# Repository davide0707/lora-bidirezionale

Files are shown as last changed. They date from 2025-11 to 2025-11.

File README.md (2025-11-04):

# Sistema di Comunicazione LoRa Bidirezionale con SCL3300
## Implementazione Embedded su STM32WLE5 (LoRa-E5 Mini) e Gateway RAK7268V2

## Abstract
Questo progetto realizza un sistema completo di comunicazione LoRaWAN bidirezionale tra una scheda LoRa-E5 Mini (STM32WLE5) e un gateway RAK7268V2. Il firmware, scritto in C con STM32CubeIDE, sostituisce integralmente il vecchio firmware AT e implementa: join OTAA autonomo, gestione uplink/downlink, acquisizione da sensore SCL3300 via SPI, calibrazione automatica, filtraggio EMA ottimizzato e pipeline di codifica/decodifica (binario → HEX → Base64). L’infrastruttura lato rete utilizza MQTT (Mosquitto) e una dashboard web per visualizzazione dati e comandi remoti. La soluzione è plug & play: una volta allineate le chiavi OTAA su gateway e firmware, la comunicazione si avvia senza ulteriori interventi.

---

## Caratteristiche
- Comunicazione LoRaWAN bidirezionale su banda EU868.
- Join OTAA già integrato nel firmware, con gestione autonoma dello stato di rete.
- Firmware custom in C (STM32CubeIDE) senza dipendenza da comandi AT.
- Driver proprietario per sensore Murata SCL3300 via SPI, con verifica WHOAMI.
- Calibrazione automatica iniziale (100 campioni) e filtro EMA sui tre assi.
- Pipeline dati: acquisizione → filtraggio → impacchettamento 16 byte → HEX → Base64.
- Dashboard web con grafico in tempo reale, log eventi e comandi remoti (es. calibrazione).
- Integrazione MQTT (Mosquitto) per telemetria e controllo.
- PCB personalizzato con LoRa-E5 + SCL3300 (circa 40 mm × 20 mm).

---

## Architettura di Sistema

[ SCL3300 (SPI) ]
│
▼
[ LoRa-E5 Mini - STM32WLE5 ]
• Firmware C
• Driver SCL3300
• EMA
• LoRaWAN (OTAA)
│ LoRa EU868
▼
[ Gateway RAK7268V2 ]
• Application (OTAA)
• Forwarder MQTT
│ Ethernet/Wi-Fi
▼
[ Broker MQTT (Mosquitto) ]
│
▼
[ Web Dashboard ]

---

## Requisiti Tecnici

### Hardware
- Scheda LoRa-E5 Mini (STM32WLE5).
- Sensore Murata SCL3300 collegato via SPI.
- Gateway LoRaWAN RAK7268V2.
- PC di sviluppo con interfaccia ST-Link o equivalente per flashing/debug.
- PCB personalizzato (opzionale, dimensioni circa 4 × 2 cm).

### Software
- STM32CubeIDE (versione recente).
- Toolchain GCC ARM Embedded integrata in STM32CubeIDE.
- Mosquitto MQTT Broker.
- Browser moderno per la dashboard web.
- Facoltativi: utilità per monitor seriale (es. PuTTY), Node.js se si estende la dashboard.

---

## Struttura del Repository

/Firmware
project (STM32CubeIDE)

/Web
interfaccia

/Docs
spiegazione dettagliata

/LICENSE
/README.md

---

## Dettagli Firmware

### Flusso di avvio
1. Inizializzazione clock, GPIO, SPI, UART/USART (log opzionale).
2. Inizializzazione stack LoRaWAN; caricamento parametri OTAA (DevEUI, AppEUI/JoinEUI, AppKey).
3. Join OTAA; al completamento, disattivazione del LED rosso lampeggiante come indicatore di rete attiva.
4. Inizializzazione SCL3300: verifica WHOAMI, settaggio modalità operativa da datasheet.
5. Calibrazione automatica: acquisizione 100 campioni, calcolo offset per X/Y/Z.
6. Loop di misura: lettura dati, applicazione filtro EMA, impacchettamento payload, invio periodico uplink. Gestione downlink per comandi remoti (es. ri-calibrazione).

### Filtro EMA
- Implementazione su ciascun asse: `y[n] = α·x[n] + (1−α)·y[n−1]`.
- Valore predefinito α tipicamente compreso tra 0,1 e 0,3 (configurabile in `app_config.h`).

### Indicatori di stato
- LED rosso lampeggiante: dispositivo in join/ricerca rete.
- LED rosso spento: join completato, rete attiva.
- Messaggi UART opzionali: log diagnostico di inizializzazione, WHOAMI, calibrazione, errori.

---

## Formato dei Dati e Codifica

### Payload binario (uplink)
- Dimensione: 16 byte totali.
- Struttura (little-endian consigliato):
  - Byte 0–3: Asse X (float IEEE-754 32-bit) oppure int32 scalato.
  - Byte 4–7: Asse Y (float 32-bit) oppure int32 scalato.
  - Byte 8–11: Asse Z (float 32-bit) oppure int32 scalato.
  - Byte 12–15: Temperatura interna (float 32-bit) oppure int32 scalato.
- Nota: per deployment a basso overhead si consiglia la rappresentazione int32 scalata (es. mdeg o mg) documentando i fattori di scala in `payload_format.md`.

### Pipeline di trasmissione
1. Acquisizione → filtraggio EMA → normalizzazione/scala → packing binario 16 byte.
2. Conversione in HEX.
3. Codifica Base64 per inoltro su MQTT, quando previsto dal flusso gateway.

### Pipeline di ricezione (lato server/dashboard)
1. Base64 → HEX → binario.
2. Parse dei 4 campi (X, Y, Z, T).
3. Applicazione fattori di scala inversi o interpretazione float IEEE-754.

### Esempio di decodifica (JavaScript, valori float 32-bit little-endian)
```js
function decodeBase64Payload(b64) {
  const raw = atob(b64); // stringa binaria
  const bytes = new Uint8Array([...raw].map(c => c.charCodeAt(0)));
  const view = new DataView(bytes.buffer);
  const x = view.getFloat32(0, true);
  const y = view.getFloat32(4, true);
  const z = view.getFloat32(8, true);
  const t = view.getFloat32(12, true);
  return { x, y, z, t };
}
```

## Comandi Remoti (Downlink)

- **Calibrazione remota**: comando per ri-avviare la sequenza di offset (100 campioni).
- **Reset filtro EMA**: re-inizializza gli stati dei tre canali.
- **Parametrizzazione**: aggiornamento del coefficiente α dell’EMA, del periodo di uplink e delle soglie di warning.

I comandi sono ricevuti e interpretati nel firmware (callback di downlink), con ack opzionale via uplink.

---

## Configurazione del Gateway RAK7268V2 (OTAA)

1. Creare un’applicazione LoRaWAN nel gateway.
2. Registrare il dispositivo in modalità OTAA, annotando **DevEUI**, **JoinEUI (AppEUI)** e **AppKey**.
3. Impostare la **regione EU868** e un profilo di data rate adeguato.
4. Abilitare l’inoltro a un **broker MQTT** (interno/esterno), specificando topic e credenziali.
5. Verificare la corrispondenza dei parametri anche nel firmware (`app_config.h`):
   - `DEV_EUI`, `JOIN_EUI`, `APP_KEY`.
6. Riavviare il nodo: al join completato, l’indicatore **LED rosso si spegne**.

---

## Build e Flash (STM32CubeIDE)

### Import del progetto
- `File → Import → Existing Projects into Workspace` → selezionare la cartella `/Firmware`.
- Verificare la toolchain (GCC for STM32) e le opzioni di ottimizzazione.

### Configurazione
- Aggiornare `app_config.h` con chiavi OTAA e parametri operativi (α EMA, periodo uplink, pin SPI).
- Verificare i pin SPI per SCL3300 (MOSI/MISO/SCK/CS) e GPIO LED.

### Compilazione e flash
- Build del progetto in modalità **Release**.
- Collegare **ST-Link**, eseguire `Run → Debug/Run`.
- Opzionale: abilitare retarget UART per log su seriale.

---

## Installazione e Avvio (Plug & Play)

1. Flash del firmware sulla **LoRa-E5 Mini**.
2. Collegamento fisico **SCL3300** su bus **SPI** come da schemi (vedi `/Docs/schematic.pdf`).
3. Configurazione del gateway **RAK7268V2** in **OTAA** con le stesse chiavi del firmware.
4. Avvio **broker Mosquitto** e, se previsto, servizio di decoding.
5. Alimentazione del nodo: il dispositivo esegue **join**, si **calibra** e avvia gli **uplink** secondo il periodo configurato.

---

## Dashboard Web

- File nella cartella `/Web` (HTML/CSS/JS, Chart.js o libreria equivalente).
- Connessione a broker **MQTT** via **WebSocket** (se abilitato) o tramite un backend di bridging.

### Visualizzazioni
- Trend di **X / Y / Z / Temperatura**.
- Log eventi (**join**, **uplink**, **downlink**).
- Stato rete e ultimo **RSSI/SNR** (se disponibili nei metadati).

### Pannello comandi
- Pulsante **calibrazione remota**.
- Impostazione parametri (**α EMA**, **periodo uplink**).

---

## Prestazioni e Considerazioni

- **Filtraggio**: l’EMA riduce il rumore preservando la dinamica; scegliere α in funzione della latenza accettabile.
- **Consumi**: per nodi a batteria, ottimizzare duty-cycle, data rate, potenza TX e sleep tra misure.
- **Affidabilità**: verificare retry LoRaWAN, conferme ACK e politiche di rejoin.
- **Sicurezza**: mantenere segrete le chiavi OTAA; usare **TLS** per il trasporto MQTT su reti pubbliche.

---

## PCB e Collegamenti

- PCB personalizzato con integrazione **LoRa-E5 + SCL3300**.
- Dimensioni indicative: **40 mm × 20 mm**.
- Vedere `/Docs/schematic.pdf` e `/Docs/pcb_layout.png` per pinout e footprint.
- Layout consigliato: tracce SPI corte, piano di massa continuo, separazione RF/analogico.

---

## Troubleshooting

- **Join non riuscito**: verificare regione **EU868**, chiavi OTAA e copertura gateway.
- **WHOAMI fallito**: controllare cablaggio SPI, CS, frequenza clock e alimentazione sensore.
- **Dati errati o saturi**: rivedere scala fisica/offset; eseguire **calibrazione remota**.
- **Dashboard vuota**: controllare connessione MQTT, topic e decoder **Base64/HEX**.

---

## Licenza

Questo progetto è distribuito con licenza **MIT**. Vedere il file `LICENSE` per i dettagli.

---

## Riferimenti

- Murata, **SCL3300 Datasheet**.
- STMicroelectronics, **STM32WLE5 Reference Manual (RM0461)** e HAL Drivers.
- LoRa Alliance, **LoRaWAN 1.0.4 Specification**.
- RAKwireless, **Documentazione RAK7268V2**.
- Eclipse Mosquitto, **Documentazione MQTT**.

---

## Autore e Contatti

<p align="center"><strong>Autore: DI FILIPPO DAVIDE</strong></p>

<!-- GitHub Profile Button -->
<div align="center" style="margin-top: 20px;">
  <a href="https://github.com/davide0707">
    
  </a>
</div>

<!-- Contact Section -->
<h3 align="center" style="margin-top: 40px; font-family: 'Arial', sans-serif; color: #2C3539; font-size: 2em;">📬 Contact Me</h3>
<div align="center" style="font-family: 'Arial', sans-serif; color: #333; margin-top: 15px;">
  <p>
    
    <strong>E-mail:</strong> difilippodavide.github@gmail.com
  </p>
  <p>
    
    <strong>GitHub:</strong> <a href="https://github.com/davide0707" style="color: #3C76D7;">davide0707</a>
  </p>
</div>

<p align="center"><strong>Anno: 2025</strong></p>

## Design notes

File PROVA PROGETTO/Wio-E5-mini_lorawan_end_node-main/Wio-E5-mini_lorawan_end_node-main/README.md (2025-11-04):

# Wio-E5-mini_lorawan_end_node
LoRaWAN End Node app built from scratch with CubeMX for STM32WLE5JCx in the Wio-E5 mini.

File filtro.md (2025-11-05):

# LoRa + SCL3300 — Calibrazione, EMA Adattivo (Scalare & Circolare) e Pipeline Dati

---

## Indice

1. [Panoramica](#panoramica)
2. [Prerequisiti & File](#prerequisiti--file)
3. [Notazione & Convenzioni](#notazione--convenzioni)
4. [Calibrazione degli offset (media statica)](#calibrazione-degli-offset-media-statica)
5. [EMA adattivo (scalare)](#ema-adattivo-scalare)
   - [Ricorrenza EMA base](#ricorrenza-ema-base)
   - [Innovazione, media/varianza esponenziale](#innovazione-mediavarianza-esponenziale)
   - [Significatività → α adattivo](#significatività--α-adattivo)
   - [Update dello stato](#update-dello-stato)
6. [EMA adattivo circolare (angoli in gradi)](#ema-adattivo-circolare-angoli-in-gradi)
   - [Wrap & distanza angolare](#wrap--distanza-angolare)
   - [Media circolare con cos/sin](#media-circolare-con-cossin)
   - [Passi d’aggiornamento](#passi-daggiornamento)
7. [Parametri, significato e trade-off](#parametri-significato-e-trade-off)
8. [Mappatura codice ⇄ matematica](#mappatura-codice--matematica)
9. [Sequenza: init, calibrazione, run](#sequenza-init-calibrazione-run)
10. [Aggiornamento periodico & log](#aggiornamento-periodico--log)
11. [Payload LoRa (opzionale)](#payload-lora-opzionale)
12. [Considerazioni numeriche & temporali](#considerazioni-numeriche--temporali)
13. [Tuning pratico passo-passo](#tuning-pratico-passo-passo)
14. [Esempi di codice](#esempi-di-codice)
15. [Debug & Troubleshooting](#debug--troubleshooting)
16. [Licenza](#licenza)

---

## Panoramica

**Obiettivo:** ottenere valori stabili e reattivi.  
Catena di elaborazione (per ogni campione):

1. **Lettura registri**: `READ_ANG_X/Y/Z`, `READ_TEMPERATURE`.
2. **Compensazione offset**: sottrazione `o_X/o_Y/o_Z` calcolati a fermo.
3. **Filtraggio:**
   - **Temperatura** → **EMA scalare** (IIR 1° ordine con α adattivo).
   - **Angoli** → **EMA circolare** (gestisce il wrap ±180°).
4. **Output**: valori filtrati su UART + (opz.) impacchettati per LoRa.

```
[SCL3300] ──► [Offset Calib] ──► [EMA-Adaptive: T] ──►
                         └──► [EMA-Circular: X/Y/Z] ──► [UART/LoRa]
```

---

## Prerequisiti & File

- MCU con SPI + UART + stack LoRa (opz.).
- File di progetto tipici:
  - `scl3300.c/.h` — driver sensore e funzioni di lettura.
  - `ema_adaptive.h/.c` — implementazione dei filtri.
  - `main.c` — init, loop, logging, payload.

---

## Notazione & Convenzioni

- **Gradi**: angoli in **°**.
- **Wrap**: intervallo **(−180, 180]**.
- **Simboli comuni**:
  - `x_k`: campione corrente
  - `y_k`: uscita filtrata
  - `α`: gain EMA (0 < α ≤ 1)
  - `β`: fattore di “memoria” per stime esponenziali (0 < β < 1)
  - `ε`: piccolo stabilizzatore numerico (es. 1e−6)

---

## Calibrazione degli offset (media statica)

**Matematica.** Con N campioni a fermo:

$$
o_X=\frac{1}{N}\sum_{i=1}^N x_i,\quad
o_Y=\frac{1}{N}\sum_{i=1}^N y_i,\quad
o_Z=\frac{1}{N}\sum_{i=1}^N z_i
$$

Compensazione per i campioni successivi:

$$
\tilde{x}_k=x_k-o_X,\quad
\tilde{y}_k=y_k-o_Y,\quad
\tilde{z}_k=z_k-o_Z
$$

**Nota pratica:** usare **N=100..300**; evitare vibrazioni; fissare il dispositivo.

---

## EMA adattivo (scalare)

### Ricorrenza EMA base

$$
y_k = y_{k-1} + \alpha\,(x_k - y_{k-1}),\quad 0<\alpha\le 1
$$

- α **grande** → più reattivo (meno smoothing)
- α **piccolo** → più liscio (più ritardo)

### Innovazione, media/varianza esponenziale

$$
\begin{aligned}
e_k &= x_k - y_{k-1} \\
m_k &= \beta\,m_{k-1} + (1-\beta)\,e_k \\
d_k &= e_k - m_k \\
s_k^2 &= \beta\,s_{k-1}^2 + (1-\beta)\,d_k^2
\end{aligned}
$$

- `m_k`: tendenza lenta dell’innovazione
- `d_k`: residuo centrato
- `s_k`: deviazione standard stimata

### Significatività → α adattivo

$$
u_k = \frac{|d_k|}{s_k + \varepsilon},\qquad
\alpha_k = \alpha_{\min} + (\alpha_{\max}-\alpha_{\min})\frac{u_k^p}{1+u_k^p}
$$

- **Quiete**: \(u\approx0 \Rightarrow \alpha\approx\alpha_{\min}\)
- **Transitorio**: \(u\gg1 \Rightarrow \alpha\rightarrow\alpha_{\max}\)

### Update dello stato

$$
y_k = y_{k-1} + \alpha_k\,(x_k - y_{k-1})
$$

---

## EMA adattivo circolare (angoli in gradi)

### Wrap & distanza angolare

Funzione wrap in \((-180,180]\):

```c
static inline float wrap_deg(float a) {
    if (a <= -180.0f) return a + 360.0f;
    if (a >  180.0f)  return a - 360.0f;
    return a;
}
```

Innovazione angolare:

$$
e_k^\theta = \mathrm{wrap}(\theta_k - y_{k-1}^\theta)
$$

> **Importante**: il calcolo di \( \alpha_k \) usa **questa** innovazione “wrapped”.

### Media circolare con cos/sin

$$
\begin{aligned}
c_k &= (1-\alpha_k)\,c_{k-1} + \alpha_k\cos(\theta_k) \\
s_k &= (1-\alpha_k)\,s_{k-1} + \alpha_k\sin(\theta_k) \\
y_k^\theta &= \mathrm{atan2}(s_k, c_k)\quad[\text{gradi}]
\end{aligned}
$$

- \((c,s)\) rappresenta coerentemente la media su cerchio.
- Si evita il “salto” 179° → −179° trattandolo come **+2°**, non **−358°**.

### Passi d’aggiornamento

1. **Errore angolare**: \( e = \mathrm{wrap}(\theta - y^\theta) \)
2. **Stime esponenziali**: \( m, s^2 \) su \( e \)
3. **u → α** (curva “soft”)
4. **Media circolare** con \( \alpha \) calcolato al punto 3.

---

## Parametri, significato e trade-off

| Parametro | Ruolo | Tipico | Effetto/Trade-off |
|---|---|---|---|
| `EMA_ALPHA_MIN`  | α in quiete | 0.02 … 0.08 | Più piccolo = più liscio ma maggiore ritardo |
| `EMA_ALPHA_MAX`  | α in transitorio | 0.3 … 0.7 | Più grande = più reattivo ma meno smoothing |
| `EMA_BETA` | memoria stime esponenziali | 0.98 … 0.995 | Alto = stima rumore più stabile ma più lenta |
| `EMA_PWR_P` | ripidità mappatura \(u\to\alpha\) | 2 (quadratico) | Più alto = transizione più brusca |
| `EMA_EPS` | stabilizzatore numerico | 1e−6 … 1e−4 | Evita div/0; non alterare troppo la dinamica |

**Regola d’oro:** inizia con *(0.04, 0.5, 0.99, 2, 1e−6)*, poi affina.

---

## Mappatura codice ⇄ matematica

| Matematica | Codice (concetto) |
|---|---|
| \( e_k = x_k - y_{k-1} \) | `e = x - y;` |
| \( m_k = \beta m_{k-1} + (1-\beta)e_k \) | `m = β*m + (1-β)*e;` |
| \( d_k = e_k - m_k \) | `de = e - m;` |
| \( s_k^2 = \beta s_{k-1}^2 + (1-\beta) d_k^2 \) | `s2 = β*s2 + (1-β)*de*de;` |
| \( u_k = |d_k|/(s_k+\varepsilon) \) | `u = fabs(de)/(sqrt(s2)+EPS);` |
| \( \alpha_k = \alpha_\min + (\alpha_\max-\alpha_\min)\frac{u^p}{1+u^p} \) | `a = αmin + (αmax-αmin)*(up/(1+up));` |
| \( y_k = y_{k-1} + \alpha_k(x_k-y_{k-1}) \) | `y += a*e;` |

---

## Sequenza: init, calibrazione, run

1. **`SCL3300_Init()`**
   - Reset/wake, setup SPI/banchi/modi.
   - Check `STATUS_SUMMARY`, `WHOAMI`.

2. **`Calibra_Offset(N)`**
   - Leggi N campioni per X/Y/Z.
   - Calcola `oX, oY, oZ`.
   - Stampa risultati.

3. **Init filtri** con valori **compensati**:
   ```c
   ema1_circdeg_init(&fx, ANG_X - oX);
   ema1_circdeg_init(&fy, ANG_Y - oY);
   ema1_circdeg_init(&fz, ANG_Z - oZ);
   ema1_adaptive_init(&ftemp, TEMP);
   ```

4. **Flag**:
   - `in_calibrazione = true` durante la media offset.
   - `sensore_pronto = true` dopo init+calibrazione.

---

## Aggiornamento periodico & log

- Eseguito se `sensore_pronto && !in_calibrazione`.
- Passi:
  1. Leggi registri.
  2. Compensa offset angoli.
  3. Aggiorna filtri (`X/Y/Z` circolare, `T` scalare).
  4. Log UART.

**Formato log (esempio):**
```
RAW  X:  12.34  Y:  -0.80  Z: 179.10  |  FILT X: 12.20  Y: -0.77  Z: -179.5  |  αx:0.056 αy:0.041 αz:0.310  |  T: 27.8°C
```

---

## Payload LoRa (opzionale)

**Consiglio**: inviare **filtrati** \(X_f, Y_f, Z_f, T_f\) per ridurre rumore e banda sprecata.

### Packing (esempio compatto 10 byte)

- Scala angoli in **centidegrees** (°×100) → `int16_t` (−18000..18000)
- Temperatura in **centi-°C** (×100) → `int16_t`
- Ordine: `Xc, Yc, Zc, Tc, Flags(α compattati opz.)`

```c
int16_t Xc = (int16_t)lrintf(Xf * 100.0f);
int16_t Yc = (int16_t)lrintf(Yf * 100.0f);
int16_t Zc = (int16_t)lrintf(Zf * 100.0f);
int16_t Tc = (int16_t)lrintf(Tf * 100.0f);

uint8_t buf[8];
memcpy(&buf[0], &Xc, 2);
memcpy(&buf[2], &Yc, 2);
memcpy(&buf[4], &Zc, 2);
memcpy(&buf[6], &Tc, 2);
// invia buf[0..7]
```

> **Nota:** se servono anche gli α istantanei, trasmetti 1 byte con `α ∈ [0,1]` quantizzato su 0..255.

---

## Considerazioni numeriche & temporali

- **Stabilità:** filtro IIR 1° con polo \(1-\alpha_k \in [1-\alpha_{\max}, 1-\alpha_{\min})\) ⇒ **sempre stabile**.
- **Ritardo medio:** circa \(\frac{1-\alpha}{\alpha}\cdot\frac{\Delta t}{2}\). Con α adattivo, il ritardo **si riduce** durante i transitori.
- **Δt non uniforme:** supportato; stimatori esponenziali sono **stazionari** rispetto al conteggio, non al tempo. Se Δt varia molto, considera α/β tempo-dipendenti.
- **Float vs double:** `float` basta su MCU; usa `sqrtf`, `atan2f`, `cosf`, `sinf`.
- **EPS:** scegli il più piccolo possibile senza instabilità (1e−6 tipico su float).

---

## Tuning pratico passo-passo

1. **Offset**: rifai la calibrazione a fermo → logga `oX/oY/oZ`.
2. **Quietezza**: osserva α in quiete; se fluttua, **aumenta β** o **riduci α_min**.
3. **Reattività**: esegui step/tilt rapido; se lento, **aumenta α_max** o **riduci β**.
4. **Overshoot/rumore**: se overshoot, **riduci α_max** o **aumenta p** (transizione più dolce).
5. **Temperatura**: di solito basta `(α_min=0.02, α_max=0.2, β=0.995, p=2)`.

---

## Esempi di codice

### Strutture & init (`ema_adaptive.h`)

```c
#ifndef EMA_ADAPTIVE_H
#define EMA_ADAPTIVE_H

#include <math.h>
#include <float.h>

#ifndef DEG2RAD
#define DEG2RAD(x) ((x) * (float)M_PI / 180.0f)
#endif
#ifndef RAD2DEG
#define RAD2DEG(x) ((x) * 180.0f / (float)M_PI)
#endif

typedef struct {
    // stime esponenziali su innovazione
    float m;      // media dell'innovazione
    float s2;     // varianza dell'innovazione
    // parametri
    float alpha_min, alpha_max;
    float beta;   // memoria per m e s2
    float p;      // potenza per mappatura u->alpha
    float eps;    // stabilizzatore numerico
    // stato filtro scalare
    float y;      // uscita filtrata
    float alpha;  // alpha corrente (utile per log)
} EMA1_Adaptive;

static inline void ema1_adaptive_init(EMA1_Adaptive *f, float y0,
                                      float alpha_min, float alpha_max,
                                      float beta, float p, float eps) {
    f->m = 0.0f;
    f->s2 = 0.0f;
    f->alpha_min = alpha_min;
    f->alpha_max = alpha_max;
    f->beta = beta;
    f->p = p;
    f->eps = eps;
    f->y = y0;
    f->alpha = alpha_min;
}

// Esegue: (1) aggiorna stime m/s2, (2) calcola alpha, (3) aggiorna y.
static inline float ema1_adaptive_update(EMA1_Adaptive *f, float x) {
    float e  = x - f->y;
    f->m     = f->beta * f->m + (1.0f - f->beta) * e;
    float de = e - f->m;
    f->s2    = f->beta * f->s2 + (1.0f - f->beta) * de * de;
    float u  = fabsf(de) / (sqrtf(f->s2) + f->eps);
    float up = (f->p == 1.0f) ? u : powf(u, f->p);
    float a  = f->alpha_min + (f->alpha_max - f->alpha_min) * (up / (1.0f + up));
    f->y    += a * e;
    f->alpha = a;
    return f->y;
}

typedef struct {
    EMA1_Adaptive core; // usa solo m/s2/alpha per adattività sugli angoli
    float c, s;         // media circolare
    float y;            // angolo filtrato [gradi]
} EMA1_CircularDeg;

static inline float wrap_deg(float a) {
    if (a <= -180.0f) return a + 360.0f;
    if (a >  180.0f)  return a - 360.0f;
    return a;
}

static inline void ema1_circdeg_init(EMA1_CircularDeg *f, float theta0,
                                     float alpha_min, float alpha_max,
                                     float beta, float p, float eps) {
    // inizializza core ma NON usa f->core.y come angolo (teniamo y separato)
    ema1_adaptive_init(&f->core, 0.0f, alpha_min, alpha_max, beta, p, eps);
    f->y = theta0;
    f->c = cosf(DEG2RAD(theta0));
    f->s = sinf(DEG2RAD(theta0));
}

// Aggiorna: calcola alpha su innovazione angolare wrapped, poi media (c,s)
static inline float ema1_circdeg_update(EMA1_CircularDeg *f, float theta_deg) {
    float e_ang = wrap_deg(theta_deg - f->y);

    // --- blocco "solo adattività": aggiorna m/s2/alpha senza modificare un y scalare ---
    // Copia minima di logica di ema1_adaptive_update ma senza il passo "y += a*e".
    float e  = e_ang;                            // innovazione angolare (deg)
    f->core.m  = f->core.beta * f->core.m + (1.0f - f->core.beta) * e;
    float de = e - f->core.m;
    f->core.s2 = f->core.beta * f->core.s2 + (1.0f - f->core.beta) * de * de;
    float u  = fabsf(de) / (sqrtf(f->core.s2) + f->core.eps);
    float up = (f->core.p == 1.0f) ? u : powf(u, f->core.p);
    float a  = f->core.alpha_min + (f->core.alpha_max - f->core.alpha_min) * (up / (1.0f + up));
    f->core.alpha = a;

    // --- media circolare con alpha calcolato ---
    float c_new = (1.0f - a) * f->c + a * cosf(DEG2RAD(theta_deg));
    float s_new = (1.0f - a) * f->s + a * sinf(DEG2RAD(theta_deg));

    // Evita degenerazione vicino a (0,0)
    const float norm = hypotf(c_new, s_new);
    if (norm > 1e-12f) {
        f->c = c_new / norm;
        f->s = s_new / norm;
    } else {
        f->c = c_new;
        f->s = s_new;
    }

    f->y = RAD2DEG(atan2f(f->s, f->c));
    return f->y;
}

#endif // EMA_ADAPTIVE_H
```

### Uso tipico nel loop

```c
// Parametri consigliati
#define A_MIN  0.04f
#define A_MAX  0.55f
#define BETA   0.990f
#define P_PWR  2.0f
#define EPS_   1e-6f

EMA1_CircularDeg fx, fy, fz;
EMA1_Adaptive    ftemp;

void filters_init(float X0, float Y0, float Z0, float T0) {
    ema1_circdeg_init(&fx, X0, A_MIN, A_MAX, BETA, P_PWR, EPS_);
    ema1_circdeg_init(&fy, Y0, A_MIN, A_MAX, BETA, P_PWR, EPS_);
    ema1_circdeg_init(&fz, Z0, A_MIN, A_MAX, BETA, P_PWR, EPS_);
    ema1_adaptive_init(&ftemp, T0, 0.02f, 0.20f, 0.995f, 2.0f, 1e-6f);
}
```

---

## Debug & Troubleshooting

- **α non scende in quiete**: alza `β` (0.995) o riduci `α_min`.
- **Filtro “moscio” ai transitori**: alza `α_max` (0.6..0.7) o abbassa `β`.
- **Oscillazioni/overshoot**: abbassa `α_max` o alza `p` (3).
- **Salti a ±180°**: assicurati di usare `wrap_deg` sull’innovazione e media circolare (cos/sin).
- **Saturazioni**: clamp α in `[α_min, α_max]`, verifica scaling LoRa.

---

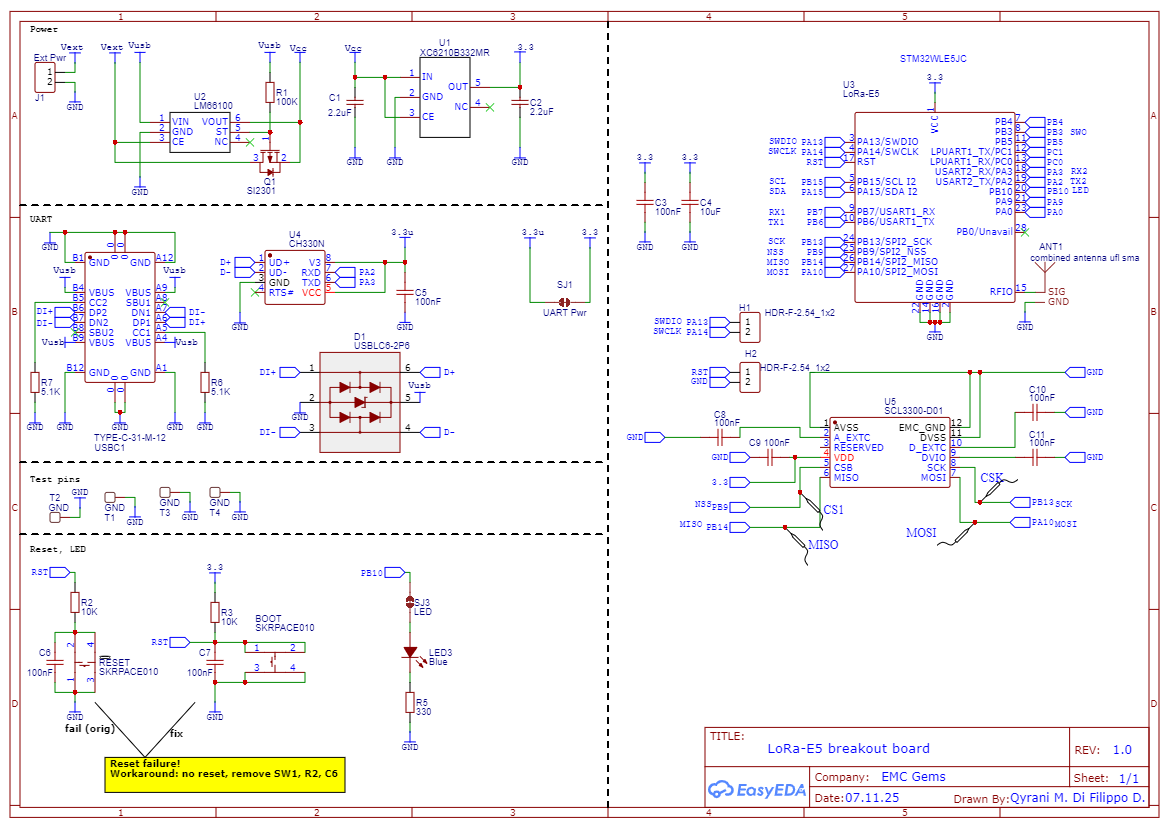
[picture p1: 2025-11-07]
pcb/Schematics/PNG_Schematic_PCB.png

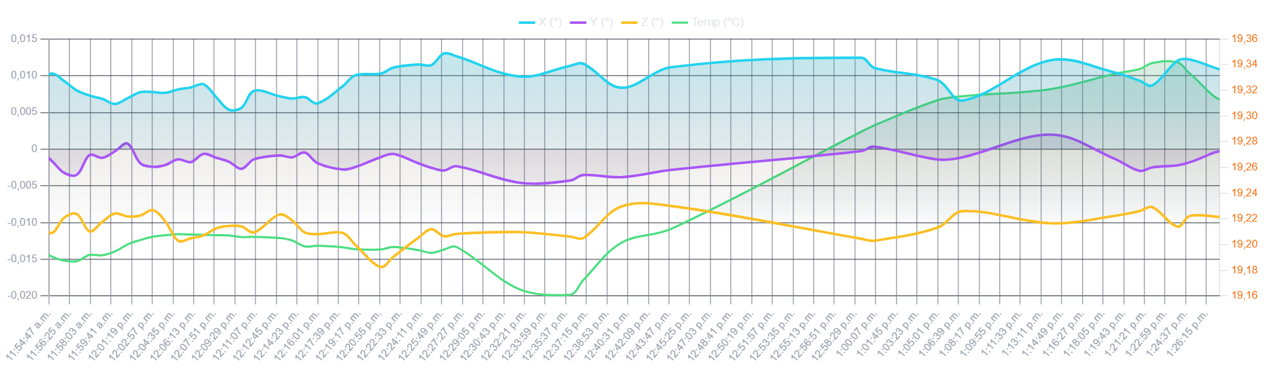
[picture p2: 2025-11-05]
INTEFACCIA/view/grafico, con zoom.png

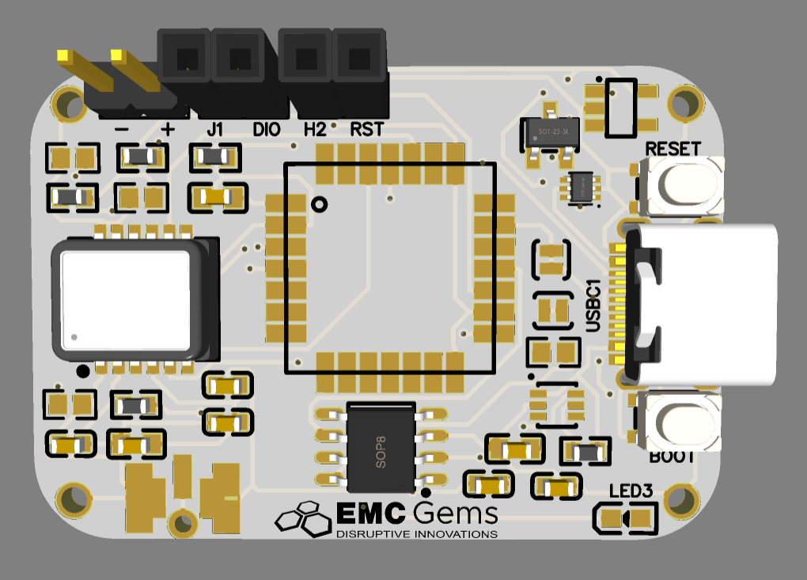
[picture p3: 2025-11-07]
pcb/Fronte PCB.png

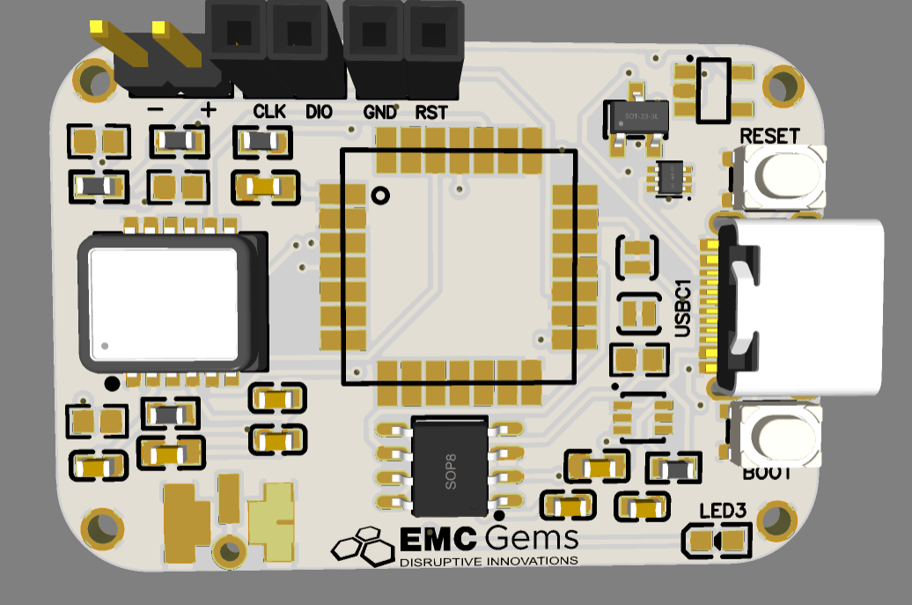
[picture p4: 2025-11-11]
pcb/Board Images/Front Side PCB.png

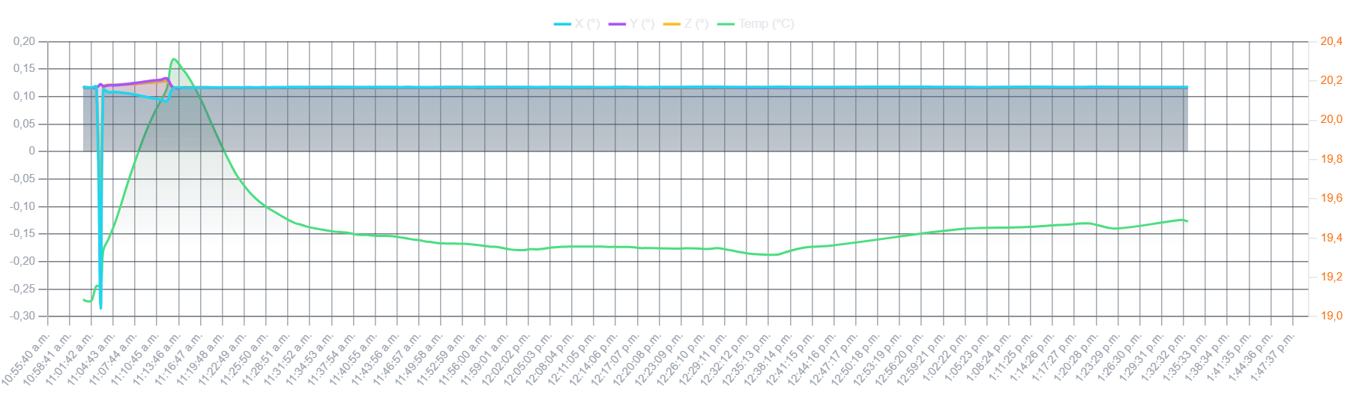
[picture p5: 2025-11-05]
INTEFACCIA/view/grafico, senza zoom.png

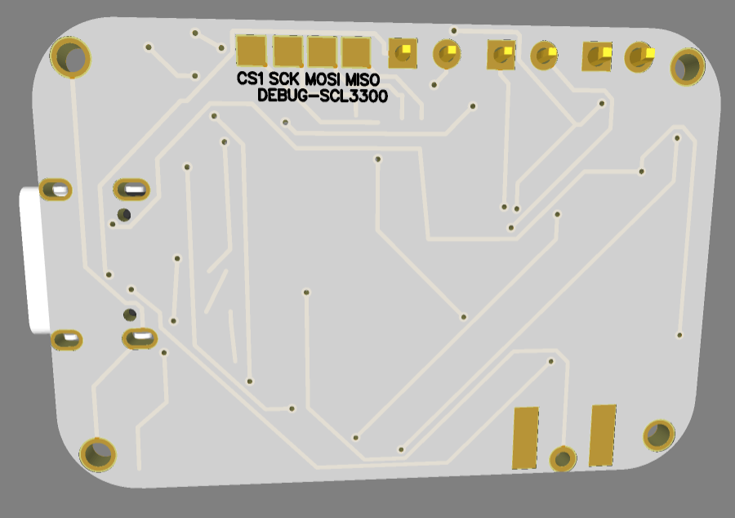
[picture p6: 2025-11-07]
pcb/Retro PCB.png

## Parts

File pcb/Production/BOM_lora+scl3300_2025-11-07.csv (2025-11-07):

ID | Name | Designator | Footprint | Quantity | Manufacturer Part | Manufacturer | Supplier | Supplier Part | Price
1 | GND | T2,T4,T1,T3 | TEST PIN | 4
2 | UART Pwr | SJ1 | PAD-JUMPER-2-NC_BY_TRACE_YES_SILK | 1
3 | LED | SJ3 | PAD-JUMPER-2-NC_BY_TRACE_YES_SILK | 1
4 | HDR-F-2.54_1x2 | H2,H1 | HDR-F-2.54_1X2 | 2 |  |  | LCSC | C49661 | 0.038
5 | Ext Pwr | J1 | HDR-M-2.54_1X2 | 1 |  |  | LCSC | C124375 | 0.025
6 | Blue | LED3 | LED-0603 | 1 | Blue light 0603 | KENTO | LCSC | C2288 | 0.01
7 | combined antenna ufl sma | ANT1 | COMBINED ANTENNA UFL SMA | 1
8 | SKRPACE010 | BOOT,RESET | KEY-SMD_4P-L4.2-W3.2-P2.20-LS4.6 | 2 | SKRPACE010 | ALPS | LCSC | C139797 | 0.06
9 | 2.2uF | C1,C2 | C0603 | 2 | CL10A225KP8NNNC | SAMSUNG | LCSC | C1607 | 0.006
10 | 100nF | C3 | C0603 | 1 | CC0603KRX7R9BB104 | YAGEO | LCSC | C14663 | 0.002
11 | 10uF | C4 | C0603 | 1 | CL10A106KP8NNNC | SAMSUNG | LCSC | C19702 | 0.006
12 | 100nF | C5,C6,C7 | 0603 | 3 | CC0603KRX7R9BB104 | YAGEO | LCSC | C14663 | 0.002
13 | 100nF | C8,C9,C10,C11 | C0603 | 4 | CL10A106KP8NNNC | SAMSUNG | LCSC | C19702 | 0.006
14 | USBLC6-2P6 | D1 | SOT-666-6_L1.6-W1.2-P0.50-LS1.6-BR | 1 | USBLC6-2P6 | STMicroelectronics | LCSC | C15999 | 0.181
15 | SI2301 | Q1 | SOT-23-3_L3.0-W1.7-P0.95-LS2.9-BR | 1 | SI2301 | PUOLOP | LCSC | C351397 | 0.021
16 | 100K | R1 | R0603 | 1 | 0603WAF1003T5E | UniOhm | LCSC | C25803 | 0.001
17 | 10K | R2,R3 | R0603 | 2 | 0603WAF1002T5E | UniOhm | LCSC | C25804 | 0.001
18 | 330 | R5 | 0603 | 1 | RC0603FR-07330RL | YAGEO | LCSC | C105881 | 0.001
19 | 5.1K | R6,R7 | R0603 | 2 | 0603WAF5101T5E | UniOhm | LCSC | C23186 | 0.001
20 | XC6210B332MR | U1 | SOT-23-5 | 1 | XC6210B332MR | TOREX | LCSC | C47719 | 0.314
21 | LM66100 | U2 | SC-70 (6) | 1 | LM66100DCK | Texas Instruments
22 | LoRa-E5 | U3 | LORA-E5 | 1 |  |  | Seedstudio
23 | CH330N | U4 | SOP-8_L4.9-W3.9-P1.27-LS6.0-BL | 1 | CH330N | WCH | LCSC | C108996 | 0.648
24 | SCL3300-D01 | U5 | DFL-12_L8.6-W7.0-P1.00-LS7.6-BL | 1 | SCL3300-D01 | muRata(村田) | LCSC | C22416657 | 48.709
25 | TYPE-C-31-M-12 | USBC1 | USB-C_SMD-TYPE-C-31-M-12 | 1 | TYPE-C-31-M-12 | Rectangular Connectors - Contacts | LCSC | C165948 | 0.175

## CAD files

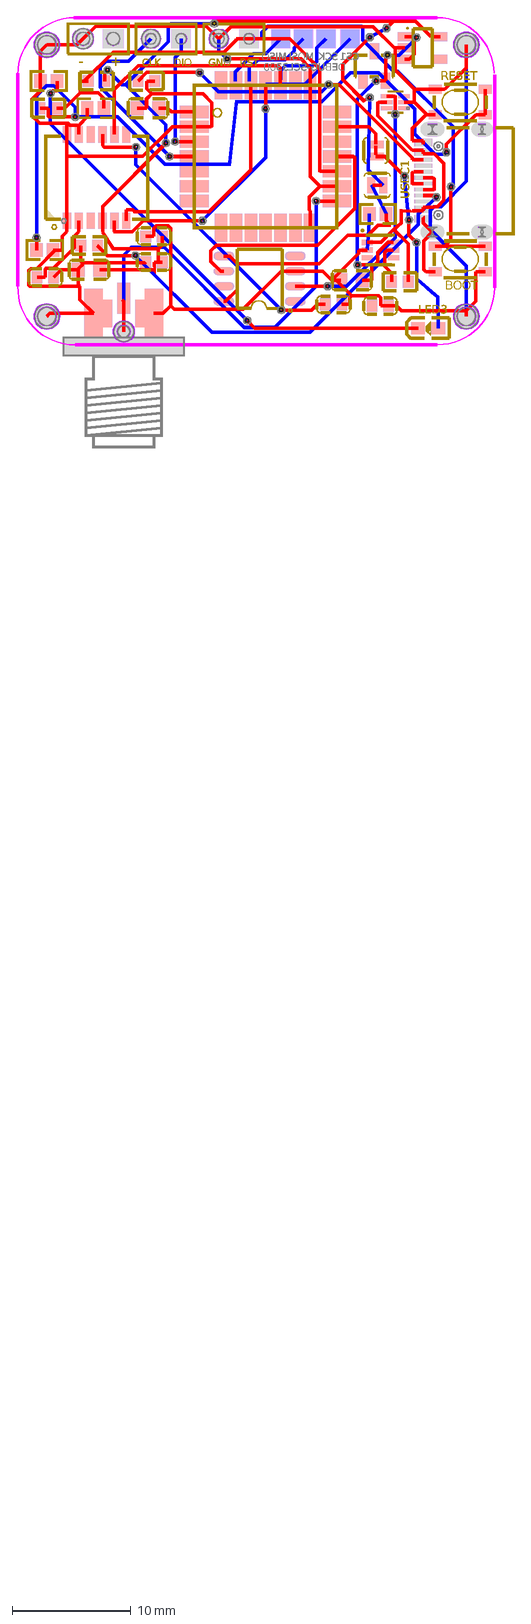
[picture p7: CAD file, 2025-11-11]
pcb/Board Breakout/PCB_LoRa-E5-breakout-board_scl+lora_2025-11-07.dxf
MISO
MOSI
SCK
DEBUG-SCL3300
CS1
RST
DIO
+
-
GND
CLK
LED3
BOOT
RESET
USBC1

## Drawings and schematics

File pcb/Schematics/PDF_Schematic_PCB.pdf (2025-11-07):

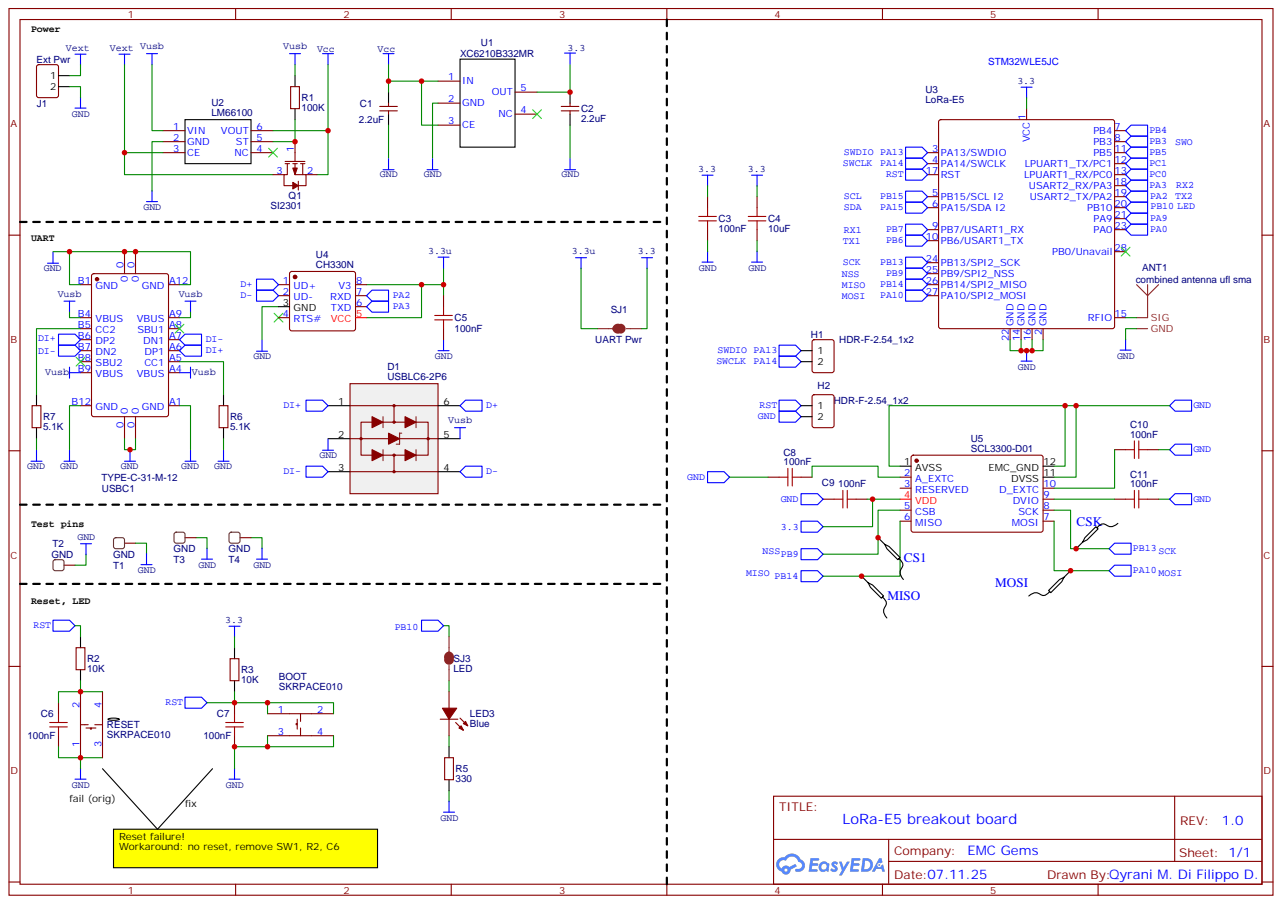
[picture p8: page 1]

combined antenna ufl sma

Reset failure!
Workaround: no reset, remove SW1, R2, C6

Drawn By:Qyrani M. Di Filippo D.

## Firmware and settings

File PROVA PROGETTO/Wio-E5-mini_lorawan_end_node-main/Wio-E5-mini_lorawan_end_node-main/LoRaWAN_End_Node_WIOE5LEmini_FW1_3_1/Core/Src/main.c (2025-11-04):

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
/* Includes ------------------------------------------------------------------*/
#include "main.h"
#include "app_lorawan.h"
#include "spi.h"
#include "gpio.h"

/* USER CODE BEGIN Includes */
#include "scl3300.h"
#include <stdio.h>
#include <string.h>
#include <stdlib.h>
/* USER CODE END Includes */


/* USER CODE BEGIN PV */
extern SCL3300_t sensor;

/* USER CODE END PV */

void SystemClock_Config(void);
/**
  * @brief  The application entry point.
  * @retval int
  */
int main(void)
{

  /* MCU Configuration--------------------------------------------------------*/

  /* Reset of all peripherals, Initializes the Flash interface and the Systick. */
  HAL_Init();

  /* Configure the system clock */
  SystemClock_Config();

  /* Initialize all configured peripherals */
  MX_GPIO_Init();
  MX_LoRaWAN_Init();
  MX_SPI2_Init();
  /* USER CODE BEGIN 2 */
  calibrazione();
  /* USER CODE END 2 */

  /* Infinite loop */
  /* USER CODE BEGIN WHILE */
  while (1)
  {
      MX_LoRaWAN_Process();

      if (sensore_pronto && !in_calibrazione)
      {
          CalcoloAngoli();
      }
      else if (!sensore_pronto)
      {
          // una sola stampa ogni tanto per debug
          static uint32_t lastMsg = 0;
          if (HAL_GetTick() - lastMsg > 3000)
          {
              printf("Sensore non ancora pronto...\r\n");
              lastMsg = HAL_GetTick();
          }
      }
  }



  /* USER CODE END 3 */
}

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


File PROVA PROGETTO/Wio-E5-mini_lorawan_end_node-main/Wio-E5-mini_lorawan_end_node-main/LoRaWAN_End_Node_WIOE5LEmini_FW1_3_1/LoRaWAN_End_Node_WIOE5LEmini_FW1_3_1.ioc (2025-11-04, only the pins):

Mcu.UserName=STM32WLE5JCIx
PA0.GPIO_Label=DBG1
PA0.Signal=GPIO_Output
PA10.Signal=SPI2_MOSI
PA13.Signal=DEBUG_JTMS-SWDIO
PA14.Signal=DEBUG_JTCK-SWCLK
PB0-VDD_TCXO.Signal=VDDTCXO
PB10.GPIO_Label=DBG2
PB10.Signal=GPIO_Output
PB13.Signal=SPI2_SCK
PB14.Signal=SPI2_MISO
PB3.GPIO_Label=DBG3
PB3.Signal=GPIO_Output
PB4.GPIO_Label=DBG4
PB4.Signal=GPIO_Output
PB5.GPIO_Label=LED2
PB5.Signal=GPIO_Output
PB6.Signal=USART1_TX
PB7.Signal=USART1_RX
PB9.Signal=GPIO_Output
PC14-OSC32_IN.Signal=RCC_OSC32_IN
PC15-OSC32_OUT.Signal=RCC_OSC32_OUT

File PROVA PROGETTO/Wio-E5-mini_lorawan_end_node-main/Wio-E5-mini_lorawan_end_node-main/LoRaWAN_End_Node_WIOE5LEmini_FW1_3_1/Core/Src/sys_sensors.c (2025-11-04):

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

/* Includes ------------------------------------------------------------------*/
#include "stdint.h"
#include "platform.h"
#include "sys_conf.h"
#include "sys_sensors.h"
#if defined (SENSOR_ENABLED) && (SENSOR_ENABLED == 0)
#include "adc_if.h"
#endif /* SENSOR_ENABLED */

/* USER CODE BEGIN Includes */
#if defined (SENSOR_ENABLED) && (SENSOR_ENABLED == 1)
#if defined (X_NUCLEO_IKS01A2)
#warning "IKS drivers are today available for several families but not stm32WL"
#warning "up to the user adapt IKS low layer to map it on WL board driver"
#warning "this code would work only if user provide necessary IKS and BSP layers"
#include "iks01a2_env_sensors.h"
#elif defined (X_NUCLEO_IKS01A3)

/*
## How to add IKS01A3 to STM32CubeWL
   Note that LoRaWAN_End_Node Example is used as an example for steps below.
 1. Open the LoRaWAN_End_Node CubeMX project by double-clicking on the LoRaWAN_End_Node.ioc under "STM32Cube_FW_WL_V1.x.x\Projects\NUCLEO-WL55JC\Applications\LoRaWAN\LoRaWAN_End_Node"
 2. From the CubeMX project, click on "Software Packs"->"Manage Software Packs" to open the Embedded Software Packages Manager. Then, click on the "STMicroelectronics" tab, expand the X-CUBE-MEMS1, check the latest version of this pack (i.e. 9.0.0), and install. Then, close the Embedded Software Packages Manager.
 3. From the CubeMX project, click on "Software Packs"->"Select Components" to open the Software Packs Component Selector, expand the X-CUBE-MEMS1 pack and select the "Board Extension IKS01A3" component by checking the respective box, and click OK.
 4. From the CubeMX project, expand the "Connectivity" category and enable I2C2 on pins PA11 (I2C2_SDA) and PA12 (I2C2_SCK).
 5. From the CubeMX project, expand the "Software Packs" category and enable the "Board Extension IKS01A3" by checking the box, and choose I2C2 under the "Found Solutions" menu.
 6. From the CubeMX project, click the "Project Manager" section
    - From the "Project Settings" section, select your Toolchain/IDE of choice (if CubeIDE, uncheck the "Generator Under Root" option).
    - From the "Code Generator" section, select "Copy only the necessary library files".
 7. Click "GENERATE CODE" to generate the code project with the MEMS drivers integrated.
 8. From the code project, find and open the sys_conf.h and make the following edits
    - Set the #define SENSOR_ENABLED to 1
    - Set the #define LOW_POWER_DISABLE to 1 to prevent the device from entering low power mode. This is needed, since the I2C2 requires handling when exiting low power modes, so to prevent issues, best is to disable low power mode, however, if low power mode is desired, you'll have to re-initialize the I2C2 from PWR_ExitStopMode() in stm32_lpm_if.c, so you can just call HAL_I2C_Init() from there.
 9. From the code project, find and open lora_app.h, and uncomment the following line
    #define CAYENNE_LPP
 10. From the code project properties, add X_NUCLEO_IKS01A3 Pre-processor Defined symbol.
 11. Save all changes and build project
 12. Connect the X-NUCLEO-IKS01A3 expansion board on the NUCLEO-WL55JC1
 13. Load and run the code
*/
#warning "IKS drivers are today available for several families but not stm32WL, follow steps defined in sys_sensors.c"
#include "iks01a3_env_sensors.h"
#else  /* not X_IKS01xx */
//#error "include_sensor_driver"
#endif  /* X_NUCLEO_IKS01xx */
#elif !defined (SENSOR_ENABLED)
#error SENSOR_ENABLED not defined
#endif  /* SENSOR_ENABLED */
/* USER CODE END Includes */

/* External variables ---------------------------------------------------------*/

/* USER CODE BEGIN PD */
#define STSOP_LATTITUDE           ((float) 43.618622 )  /*!< default latitude position */
#define STSOP_LONGITUDE           ((float) 7.051415  )  /*!< default longitude position */
#define MAX_GPS_POS               ((int32_t) 8388607 )  /*!< 2^23 - 1 */
#define HUMIDITY_DEFAULT_VAL      50.0f                 /*!< default humidity */
#define TEMPERATURE_DEFAULT_VAL   18.0f                 /*!< default temperature */
#define PRESSURE_DEFAULT_VAL      1000.0f               /*!< default pressure */
/* USER CODE END PD */


/* USER CODE BEGIN PV */
#if defined (SENSOR_ENABLED) && (SENSOR_ENABLED == 1)
#if defined (X_NUCLEO_IKS01A2)
#warning "IKS drivers are today available for several families but not stm32WL"
#warning "up to the user adapt IKS low layer to map it on WL board driver"
#warning "this code would work only if user provide necessary IKS and BSP layers"
IKS01A2_ENV_SENSOR_Capabilities_t EnvCapabilities;
#elif defined (X_NUCLEO_IKS01A3)
IKS01A3_ENV_SENSOR_Capabilities_t EnvCapabilities;
#else  /* not X_IKS01Ax */
//#error include_sensor_driver
#endif  /* X_NUCLEO_IKS01 */
#elif !defined (SENSOR_ENABLED)
#error SENSOR_ENABLED not defined
#endif  /* SENSOR_ENABLED */
/* USER CODE END PV */

/* Exported functions --------------------------------------------------------*/
int32_t EnvSensors_Read(sensor_t *sensor_data)
{
  /* USER CODE BEGIN EnvSensors_Read */
  float HUMIDITY_Value = HUMIDITY_DEFAULT_VAL;
  float TEMPERATURE_Value = TEMPERATURE_DEFAULT_VAL;
  float PRESSURE_Value = PRESSURE_DEFAULT_VAL;

#if defined (SENSOR_ENABLED) && (SENSOR_ENABLED == 1)
#if (USE_IKS01A2_ENV_SENSOR_HTS221_0 == 1)
  IKS01A2_ENV_SENSOR_GetValue(HTS221_0, ENV_HUMIDITY, &HUMIDITY_Value);
  IKS01A2_ENV_SENSOR_GetValue(HTS221_0, ENV_TEMPERATURE, &TEMPERATURE_Value);
#endif /* USE_IKS01A2_ENV_SENSOR_HTS221_0 */
#if (USE_IKS01A2_ENV_SENSOR_LPS22HB_0 == 1)
  IKS01A2_ENV_SENSOR_GetValue(LPS22HB_0, ENV_PRESSURE, &PRESSURE_Value);
  IKS01A2_ENV_SENSOR_GetValue(LPS22HB_0, ENV_TEMPERATURE, &TEMPERATURE_Value);
#endif /* USE_IKS01A2_ENV_SENSOR_LPS22HB_0 */
#if (USE_IKS01A3_ENV_SENSOR_HTS221_0 == 1)
  IKS01A3_ENV_SENSOR_GetValue(IKS01A3_HTS221_0, ENV_HUMIDITY, &HUMIDITY_Value);
  IKS01A3_ENV_SENSOR_GetValue(IKS01A3_HTS221_0, ENV_TEMPERATURE, &TEMPERATURE_Value);
#endif /* USE_IKS01A3_ENV_SENSOR_HTS221_0 */
#if (USE_IKS01A3_ENV_SENSOR_LPS22HH_0 == 1)
  IKS01A3_ENV_SENSOR_GetValue(IKS01A3_LPS22HH_0, ENV_PRESSURE, &PRESSURE_Value);
  IKS01A3_ENV_SENSOR_GetValue(IKS01A3_LPS22HH_0, ENV_TEMPERATURE, &TEMPERATURE_Value);
#endif /* USE_IKS01A3_ENV_SENSOR_LPS22HH_0 */
#else
  TEMPERATURE_Value = (SYS_GetTemperatureLevel() >> 8);
#endif  /* SENSOR_ENABLED */

  sensor_data->humidity    = HUMIDITY_Value;
  sensor_data->temperature = TEMPERATURE_Value;
  sensor_data->pressure    = PRESSURE_Value;

  sensor_data->latitude  = (int32_t)((STSOP_LATTITUDE  * MAX_GPS_POS) / 90);
  sensor_data->longitude = (int32_t)((STSOP_LONGITUDE  * MAX_GPS_POS) / 180);

  return 0;
  /* USER CODE END EnvSensors_Read */
}

int32_t EnvSensors_Init(void)
{
  int32_t ret = 0;
  /* USER CODE BEGIN EnvSensors_Init */
#if defined (SENSOR_ENABLED) && (SENSOR_ENABLED == 1)
  /* Init */
#if (USE_IKS01A2_ENV_SENSOR_HTS221_0 == 1)
  ret = IKS01A2_ENV_SENSOR_Init(HTS221_0, ENV_TEMPERATURE | ENV_HUMIDITY);
  if (ret != BSP_ERROR_NONE)
  {
    Error_Handler();
  }
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

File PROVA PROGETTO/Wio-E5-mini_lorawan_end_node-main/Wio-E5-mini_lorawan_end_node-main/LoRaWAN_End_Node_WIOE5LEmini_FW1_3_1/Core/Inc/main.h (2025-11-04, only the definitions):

#define RTC_PREDIV_A ((1<<(15-RTC_N_PREDIV_S))-1)
#define RTC_N_PREDIV_S 10
#define RTC_PREDIV_S ((1<<RTC_N_PREDIV_S)-1)
#define DBG3_Pin GPIO_PIN_3
#define DBG3_GPIO_Port GPIOB
#define DBG4_Pin GPIO_PIN_4
#define DBG4_GPIO_Port GPIOB
#define LED2_Pin GPIO_PIN_5
#define LED2_GPIO_Port GPIOB
#define DBG1_Pin GPIO_PIN_0
#define DBG1_GPIO_Port GPIOA
#define DBG2_Pin GPIO_PIN_10
#define DBG2_GPIO_Port GPIOB

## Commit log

2025-11-04 Add STM32 project under 'CON SPI, FISICO' folder
2025-11-07 Eliminato File Sbagliato
    [PCB_LoRa-E5-breakout-board_scl+lora_2025-11-07.dxf]
2025-11-07 Add README for Board Breakout
2025-11-07 Add README for Board Schematics
2025-11-11 Ripristinata cartella pcb dal commit 9515ef3
    [BOM_lora+scl3300_2025-11-07.csv, PCB_LoRa-E5-breakout-board_scl+lora_2025-11-07.dxf]

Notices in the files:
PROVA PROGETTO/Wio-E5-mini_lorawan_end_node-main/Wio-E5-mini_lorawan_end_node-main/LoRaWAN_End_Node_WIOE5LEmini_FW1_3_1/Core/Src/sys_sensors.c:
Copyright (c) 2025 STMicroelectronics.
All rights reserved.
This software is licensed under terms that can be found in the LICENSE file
